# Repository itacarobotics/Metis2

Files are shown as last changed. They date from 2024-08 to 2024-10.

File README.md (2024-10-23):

# Metis2
Metis2 is the latest enhanced version of Metis. This project is currently under development, however below is an overview of the changes.

## Mechanics
The new delta robot provides a modular design, with less components and assembly time. An extra degree of freedom has been added to the end effector to rotate around the z-axis. Furthermore, the size of the new robot is significantly smaller than the previous one, therefore it can better fits in smaller environments, such as a small production line.

## Electronics
The control unit of the robot is the BIGTREETECH-SKR-mini-E3 board, which is a main board for 3D printers. Beyond that, a custom PCB has been designed as a shield for the main board, in order to better manage GPIOs and power supply for encoders and motors using terminal blocks.

## Firmware
The control software of the robot is subdivided in two parts based on abstraction levels. The low-level firmware runs on an STM32-G01B1RCT6 micro-controller integrated onto the motherboard. The firmware runs different state machines, each responisble for the comunication, processing data for the trajectory generation and inverse geometry and controlling the closed loop stepper motors. The higher level software controls the position of the robot using the GCODE format.

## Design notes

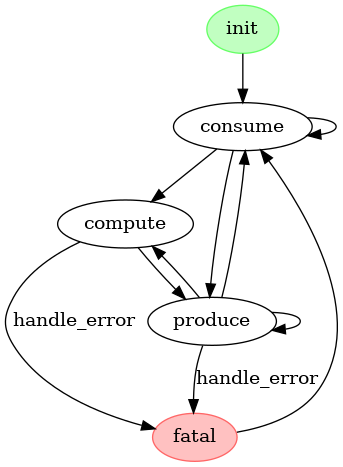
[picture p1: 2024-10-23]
firmware/assets/gv_fsm/_fsm_middleware.dot.png

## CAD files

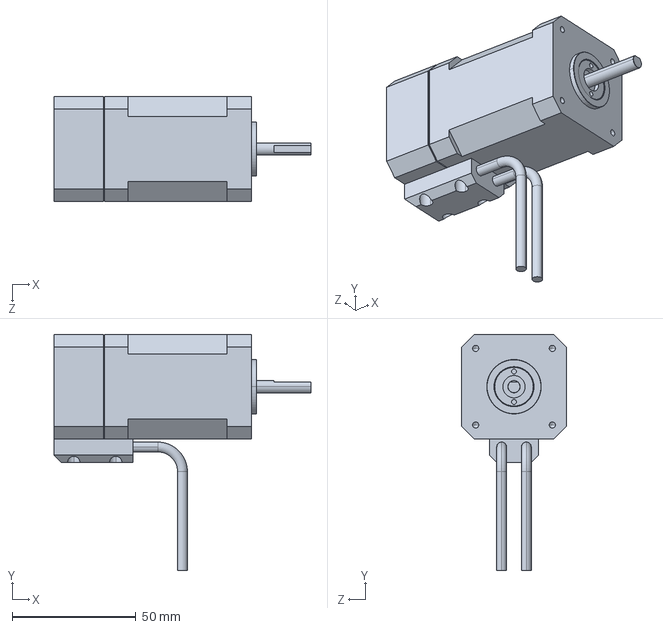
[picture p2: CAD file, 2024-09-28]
doc/motors/17HS24-2004D-E1K/17HS24-2004D-E1K.STEP
104.0 x 95.5 x 42.3 mm

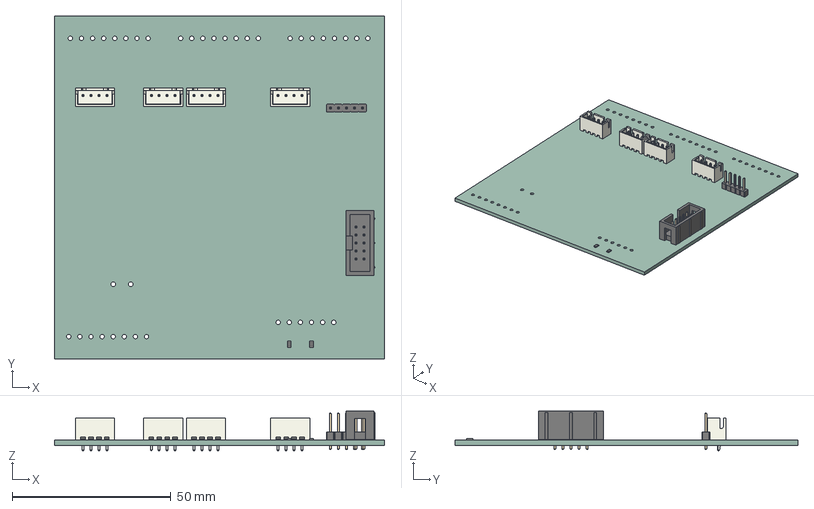
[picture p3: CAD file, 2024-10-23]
hardware/BTT-SKR-MINI-E3_shield/BTT-SKR-MINI-E3_shield.step
104.0 x 108.0 x 12.5 mm
JST_B4B_XH_A x 4
R_0805_2012Metric x 2
PinHeader_1x05_P254mm_Vertical
IDC_Header_2x05_P254mm_Vertical
BTT-SKR-MINI-E3_shield_PCB

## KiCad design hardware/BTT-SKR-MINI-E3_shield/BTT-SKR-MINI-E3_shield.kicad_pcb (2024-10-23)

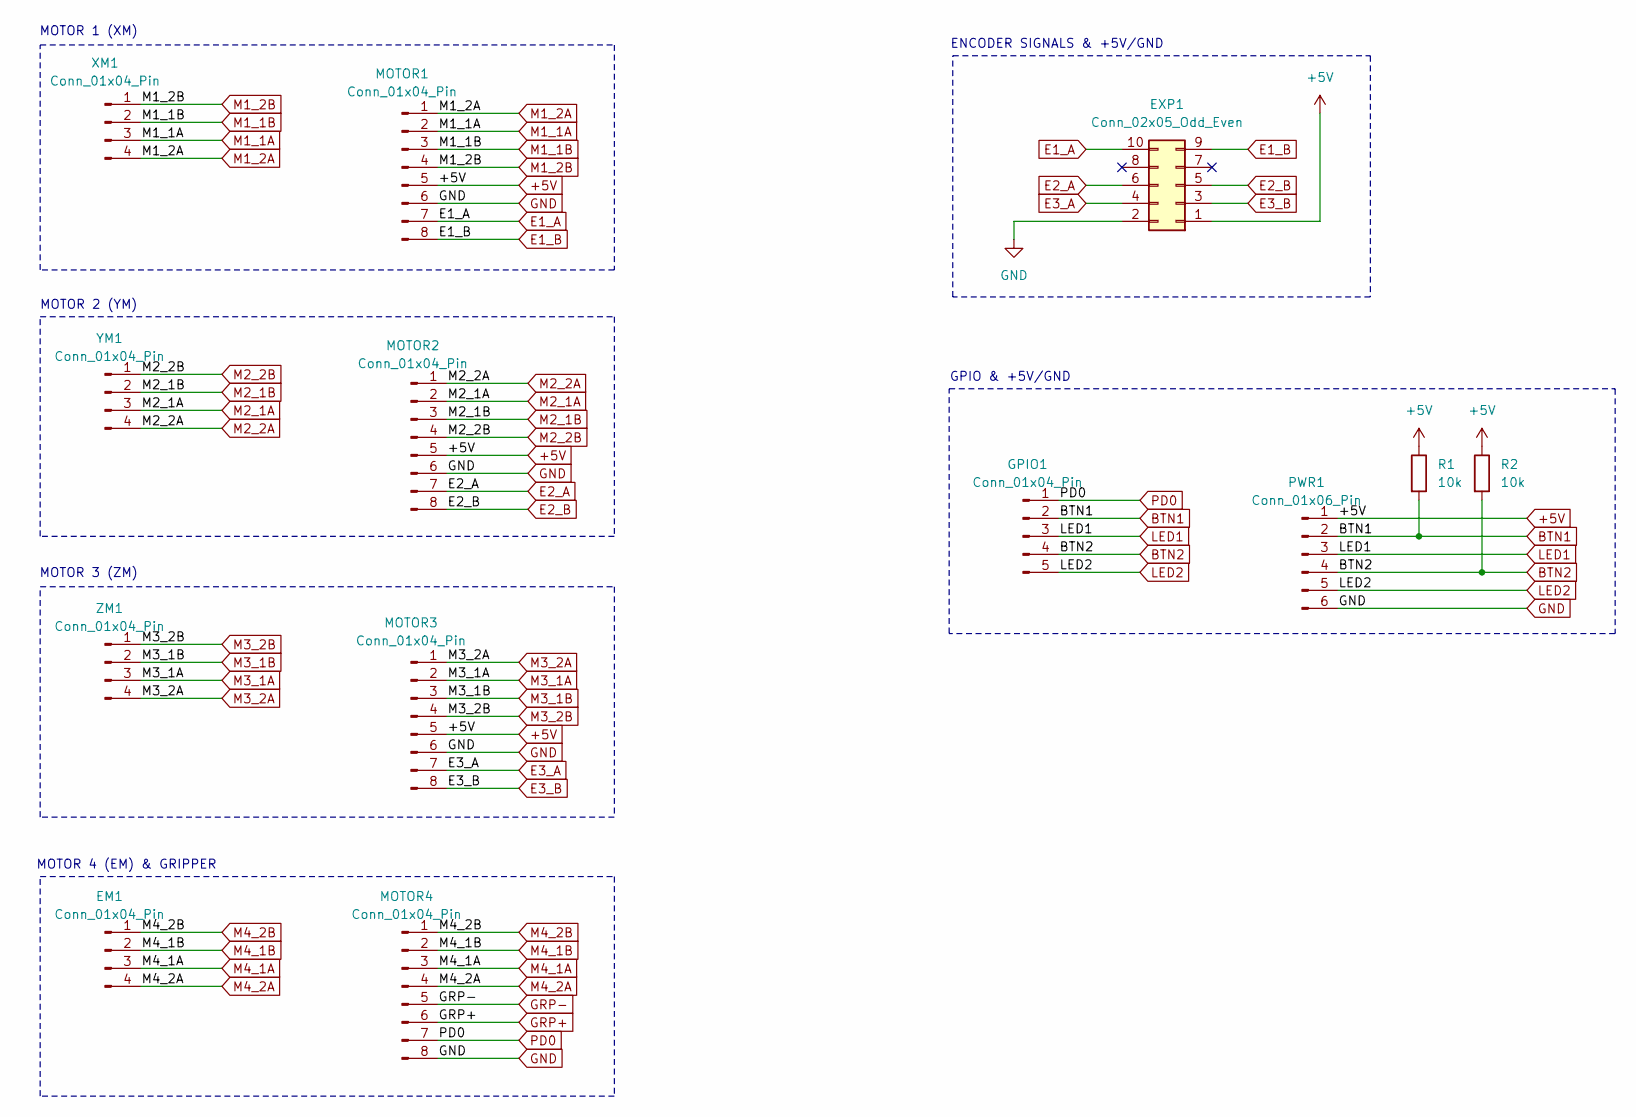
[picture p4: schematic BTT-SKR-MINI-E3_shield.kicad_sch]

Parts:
EM1: Conn_01x04_Pin; JST_XH_B4B-XH-A_1x04_P2.50mm_Vertical
EXP1: Conn_02x05_Odd_Even; IDC-Header_2x05_P2.54mm_Vertical
GPIO1: Conn_01x04_Pin; PinHeader_1x05_P2.54mm_Vertical
MOTOR1, MOTOR2, MOTOR3, MOTOR4: Conn_01x04_Pin; MC1.5_8-G-3.5
PWR1: Conn_01x06_Pin; MV1.5_6-G-3.5
R1, R2: 10k; R_0805_2012Metric
XM1: Conn_01x04_Pin; JST_XH_B4B-XH-A_1x04_P2.50mm_Vertical
YM1: Conn_01x04_Pin; JST_XH_B4B-XH-A_1x04_P2.50mm_Vertical
ZM1: Conn_01x04_Pin; JST_XH_B4B-XH-A_1x04_P2.50mm_Vertical

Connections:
+5V: EXP1.1, MOTOR1.5, MOTOR2.5, MOTOR3.5, PWR1.1, R1.1, R2.1
BTN1: GPIO1.2, PWR1.2, R1.2
BTN2: GPIO1.4, PWR1.4, R2.2
E1_A: EXP1.10, MOTOR1.7
E1_B: EXP1.9, MOTOR1.8
E2_A: EXP1.6, MOTOR2.7
E2_B: EXP1.5, MOTOR2.8
E3_A: EXP1.4, MOTOR3.7
E3_B: EXP1.3, MOTOR3.8
GND: EXP1.2, MOTOR1.6, MOTOR2.6, MOTOR3.6, MOTOR4.8, PWR1.6
GRP+: MOTOR4.6; also elsewhere on the board
GRP-: MOTOR4.5; also elsewhere on the board
LED1: GPIO1.3, PWR1.3
LED2: GPIO1.5, PWR1.5
M1_1A: MOTOR1.2, XM1.3
M1_1B: MOTOR1.3, XM1.2
M1_2A: MOTOR1.1, XM1.4
M1_2B: MOTOR1.4, XM1.1
M2_1A: MOTOR2.2, YM1.3
M2_1B: MOTOR2.3, YM1.2
M2_2A: MOTOR2.1, YM1.4
M2_2B: MOTOR2.4, YM1.1
M3_1A: MOTOR3.2, ZM1.3
M3_1B: MOTOR3.3, ZM1.2
M3_2A: MOTOR3.1, ZM1.4
M3_2B: MOTOR3.4, ZM1.1
M4_1A: EM1.3, MOTOR4.3
M4_1B: EM1.2, MOTOR4.2
M4_2A: EM1.4, MOTOR4.4
M4_2B: EM1.1, MOTOR4.1
PD0: GPIO1.1, MOTOR4.7

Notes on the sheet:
ENCODER SIGNALS & +5V/GND
MOTOR 3 (ZM)
MOTOR 4 (EM) & GRIPPER
MOTOR 1 (XM)
GPIO & +5V/GND
MOTOR 2 (YM)

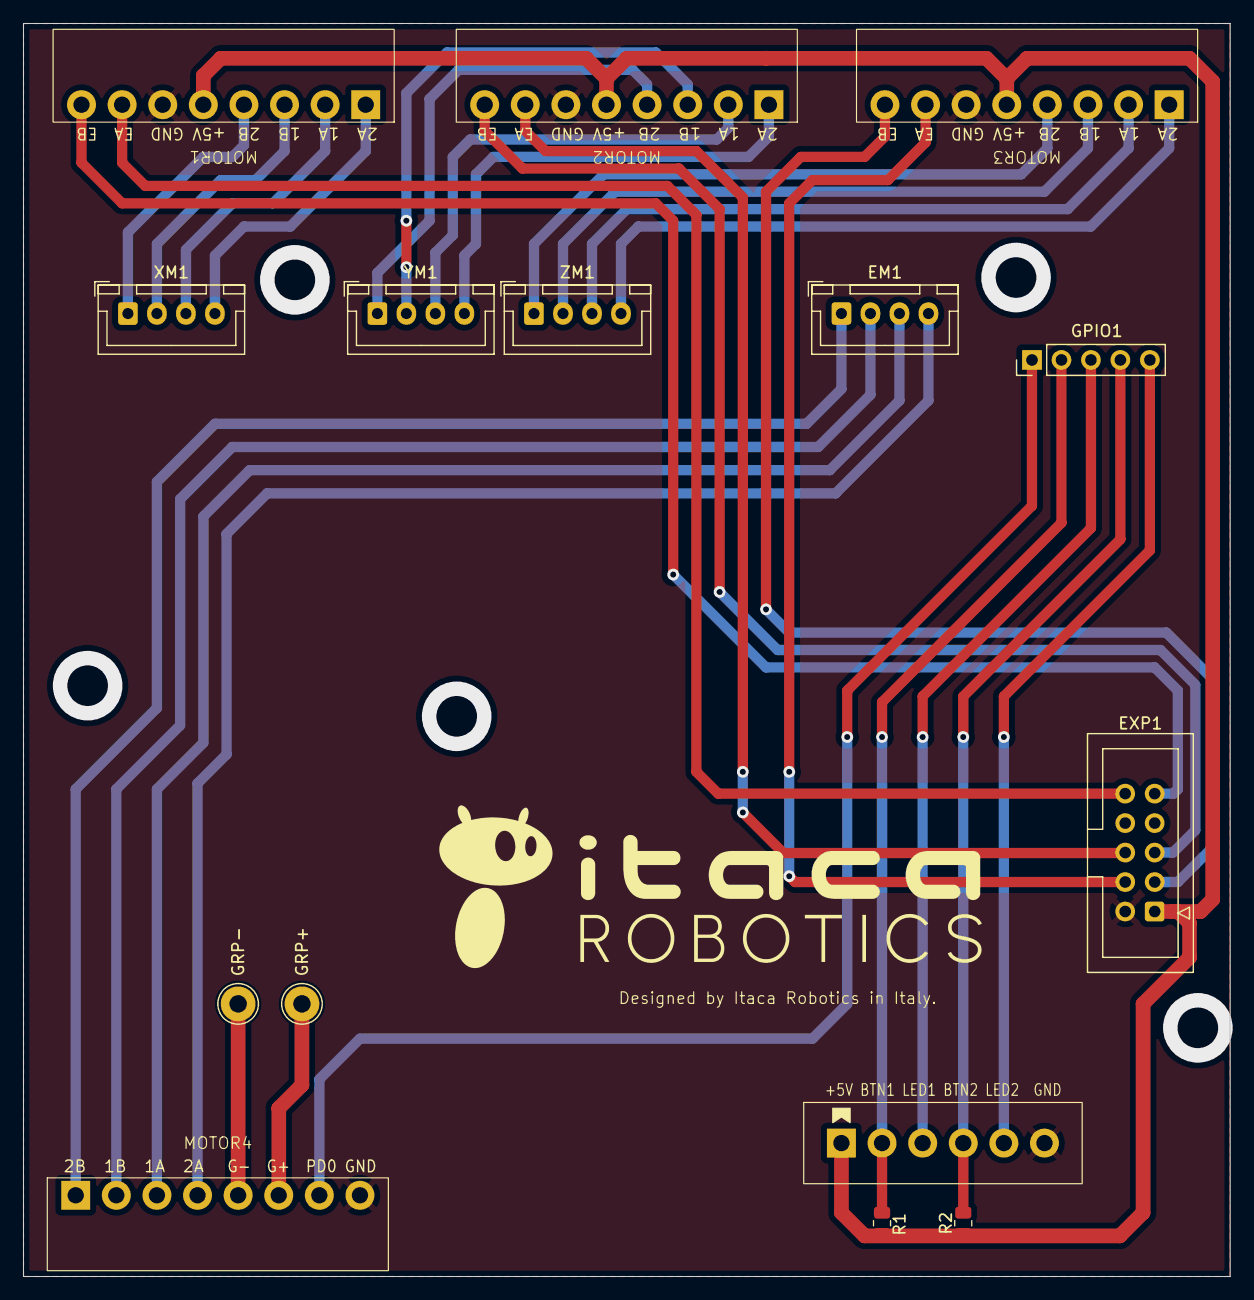
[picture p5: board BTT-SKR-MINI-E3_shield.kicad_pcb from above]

Board: 2 copper layers, 104.0 x 108.0 mm, 15 parts (0 on the bottom side), 31 nets.

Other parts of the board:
GRP+: TestPoint_THTPad_D3.0mm_Drill1.5mm
GRP-: TestPoint_THTPad_D3.0mm_Drill1.5mm

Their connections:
GRP+: GRP+.1; also elsewhere on the board
GRP-: GRP-.1; also elsewhere on the board

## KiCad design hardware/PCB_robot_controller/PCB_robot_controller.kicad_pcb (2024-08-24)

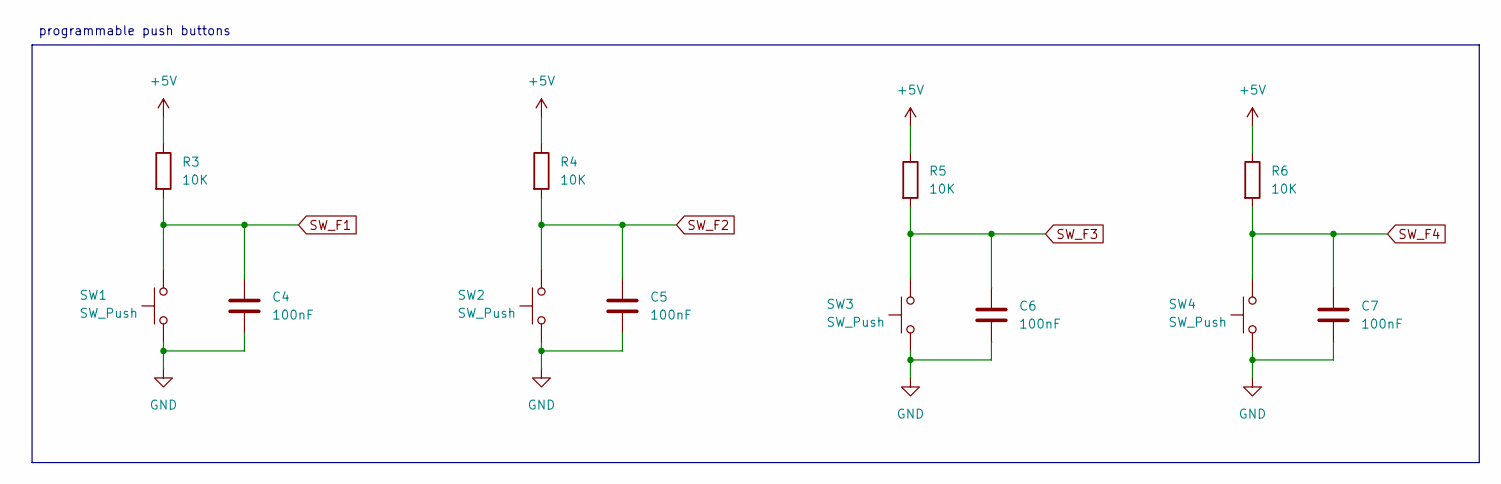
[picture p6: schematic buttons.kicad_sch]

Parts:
C4, C5, C6, C7: 100nF; C_0805_2012Metric
R3, R4, R5, R6: 10K; R_0805_2012Metric
SW1, SW2, SW3, SW4: SW_Push; SW_PUSH_6mm_H5mm

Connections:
+5V: R3.1, R4.1, R5.1, R6.1; also elsewhere on the board
GND: C4.2, C5.2, C6.2, C7.2, SW1.1, SW2.1, SW3.1, SW4.1; also elsewhere on the board
SW_F1: C4.1, R3.2, SW1.2; also elsewhere on the board
SW_F2: C5.1, R4.2, SW2.2; also elsewhere on the board
SW_F3: C6.1, R5.2, SW3.2; also elsewhere on the board
SW_F4: C7.1, R6.2, SW4.2; also elsewhere on the board

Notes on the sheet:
programmable push buttons

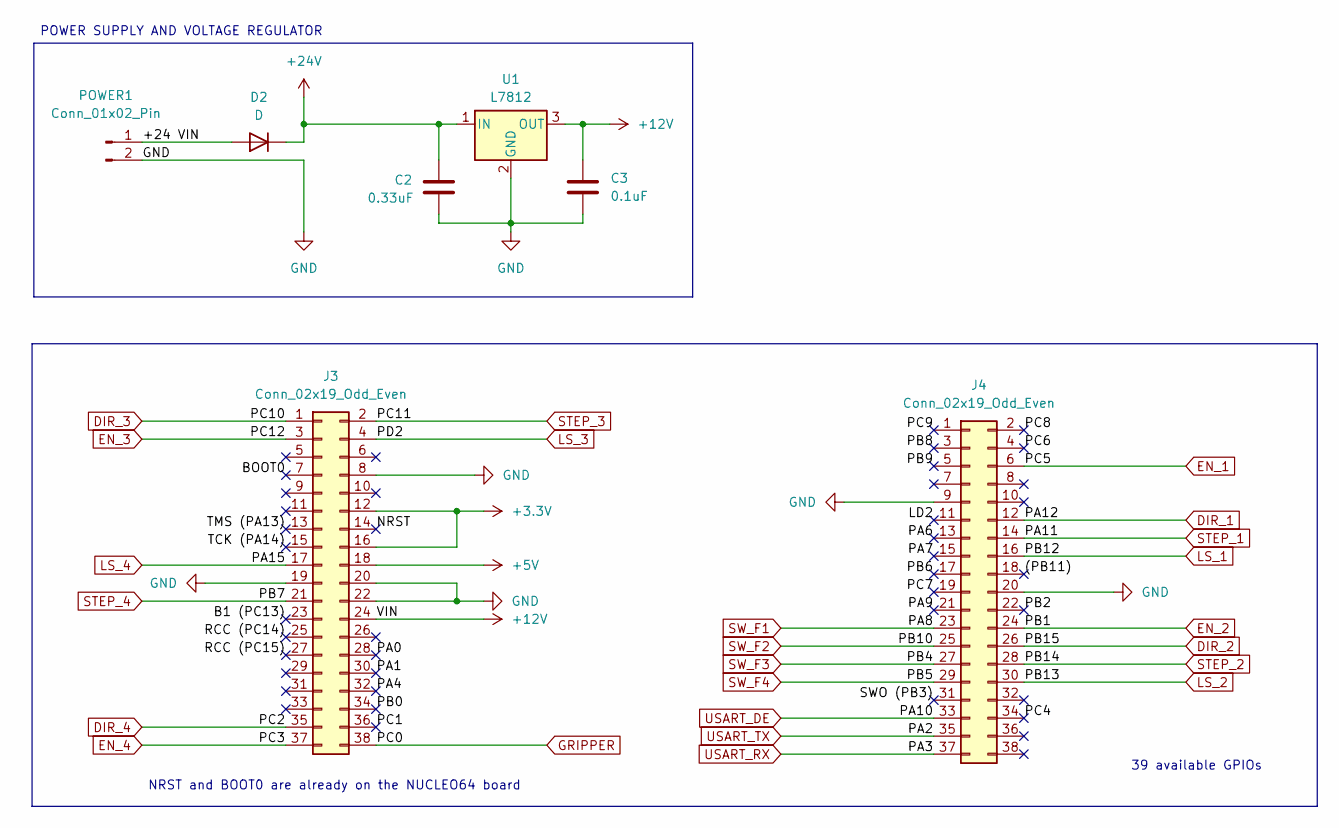
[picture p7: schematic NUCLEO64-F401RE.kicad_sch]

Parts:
C2: 0.33uF; C_0805_2012Metric
C3: 0.1uF; C_0805_2012Metric
D2: D; D_0805_2012Metric
J3, J4: Conn_02x19_Odd_Even; PinSocket_2x19_P2.54mm_Vertical
POWER1: Conn_01x02_Pin; TerminalBlock 45 degrees, pitch 3.5mm, 2 pins, WAGO 250-102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
U1: L7812; TO-220-3_Horizontal_TabDown

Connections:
+3.3V: J3.12, J3.16
+5V: J3.18; also elsewhere on the board
+12V: C3.1, J3.24, U1.3 (OUT)
+24V: C2.1, D2.1 (K), U1.1 (IN); also elsewhere on the board
/NUCLEO64-F401RE/(PB11): J4.18
/NUCLEO64-F401RE/+24 VIN: D2.2 (A), POWER1.1; also elsewhere on the board
/NUCLEO64-F401RE/B1 (PC13): J3.23
/NUCLEO64-F401RE/BOOT0: J3.7
/NUCLEO64-F401RE/LD2: J4.11
/NUCLEO64-F401RE/NRST: J3.14
/NUCLEO64-F401RE/PA0: J3.28
/NUCLEO64-F401RE/PA1: J3.30
/NUCLEO64-F401RE/PA4: J3.32
/NUCLEO64-F401RE/PA6: J4.13
/NUCLEO64-F401RE/PA7: J4.15
/NUCLEO64-F401RE/PA9: J4.21
/NUCLEO64-F401RE/PB0: J3.34
/NUCLEO64-F401RE/PB2: J4.22
/NUCLEO64-F401RE/PB6: J4.17
/NUCLEO64-F401RE/PB8: J4.3
/NUCLEO64-F401RE/PB9: J4.5
/NUCLEO64-F401RE/PC1: J3.36
/NUCLEO64-F401RE/PC4: J4.34
/NUCLEO64-F401RE/PC6: J4.4
/NUCLEO64-F401RE/PC7: J4.19
/NUCLEO64-F401RE/PC8: J4.2
/NUCLEO64-F401RE/PC9: J4.1
/NUCLEO64-F401RE/RCC (PC14): J3.25
/NUCLEO64-F401RE/RCC (PC15): J3.27
/NUCLEO64-F401RE/SWO (PB3): J4.31
/NUCLEO64-F401RE/TCK (PA14): J3.15
/NUCLEO64-F401RE/TMS (PA13): J3.13
DIR_1: J4.12; also elsewhere on the board
DIR_2: J4.26; also elsewhere on the board
DIR_3: J3.1; also elsewhere on the board
DIR_4: J3.35; also elsewhere on the board
EN_1: J4.6; also elsewhere on the board
EN_2: J4.24; also elsewhere on the board
EN_3: J3.3; also elsewhere on the board
EN_4: J3.37; also elsewhere on the board
GND: C2.2, C3.2, J3.8, J3.19, J3.20, J3.22, J4.9, J4.20, POWER1.2, U1.2 (GND); also elsewhere on the board
GRIPPER: J3.38; also elsewhere on the board
LS_1: J4.16; also elsewhere on the board
LS_2: J4.30; also elsewhere on the board
LS_3: J3.4; also elsewhere on the board
LS_4: J3.17; also elsewhere on the board
STEP_1: J4.14; also elsewhere on the board
STEP_2: J4.28; also elsewhere on the board
STEP_3: J3.2; also elsewhere on the board
STEP_4: J3.21; also elsewhere on the board
SW_F1: J4.23; also elsewhere on the board
SW_F2: J4.25; also elsewhere on the board
SW_F3: J4.27; also elsewhere on the board
SW_F4: J4.29; also elsewhere on the board
USART_DE: J4.33; also elsewhere on the board
USART_RX: J4.37; also elsewhere on the board
USART_TX: J4.35; also elsewhere on the board

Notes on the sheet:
39 available GPIOs
POWER SUPPLY AND VOLTAGE REGULATOR
NRST and BOOT0 are already on the NUCLEO64 board

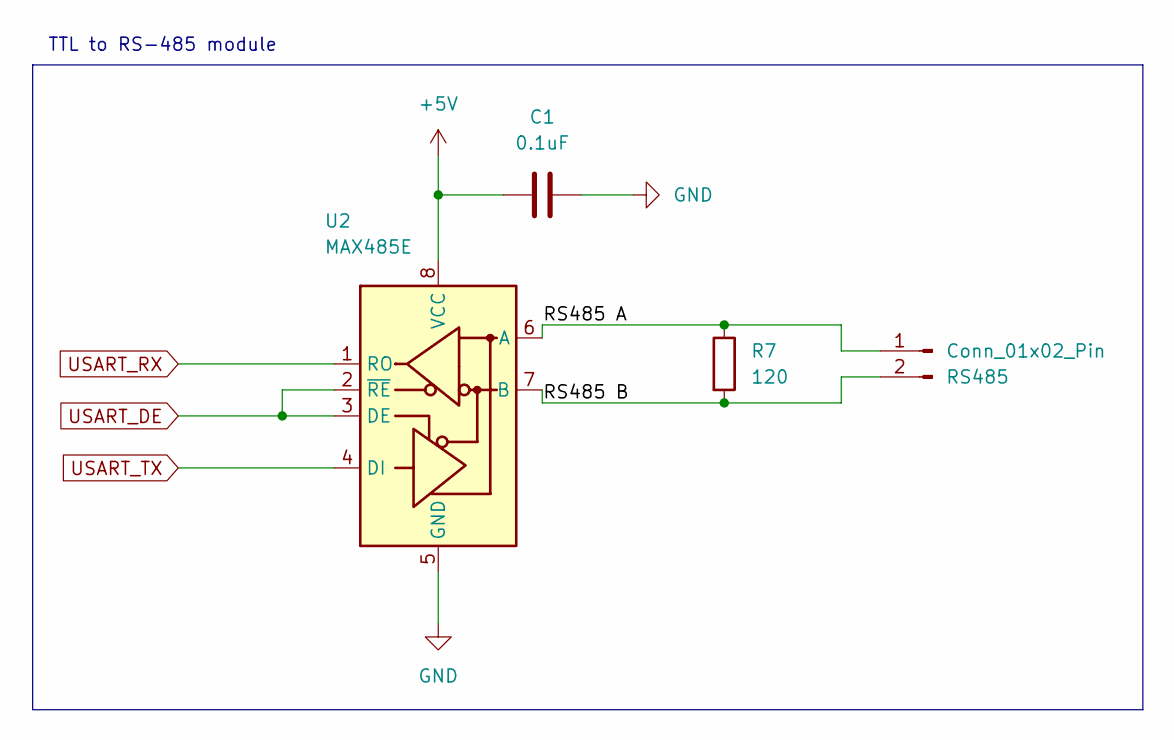
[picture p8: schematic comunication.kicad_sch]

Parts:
C1: 0.1uF; C_0805_2012Metric
R7: 120; R_0805_2012Metric
RS485: Conn_01x02_Pin; TerminalBlock 45 degrees, pitch 3.5mm, 2 pins, WAGO 250-102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
U2: MAX485E; SO-8_3.9x4.9mm_P1.27mm

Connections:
+5V: C1.1, U2.8 (VCC); also elsewhere on the board
/comunication/RS485 A: R7.1, RS485.1, U2.6 (A); also elsewhere on the board
/comunication/RS485 B: R7.2, RS485.2, U2.7 (B); also elsewhere on the board
GND: C1.2, U2.5 (GND); also elsewhere on the board
USART_DE: U2.2 (~RE), U2.3 (DE); also elsewhere on the board
USART_RX: U2.1 (RO); also elsewhere on the board
USART_TX: U2.4 (DI); also elsewhere on the board

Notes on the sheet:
TTL to RS-485 module

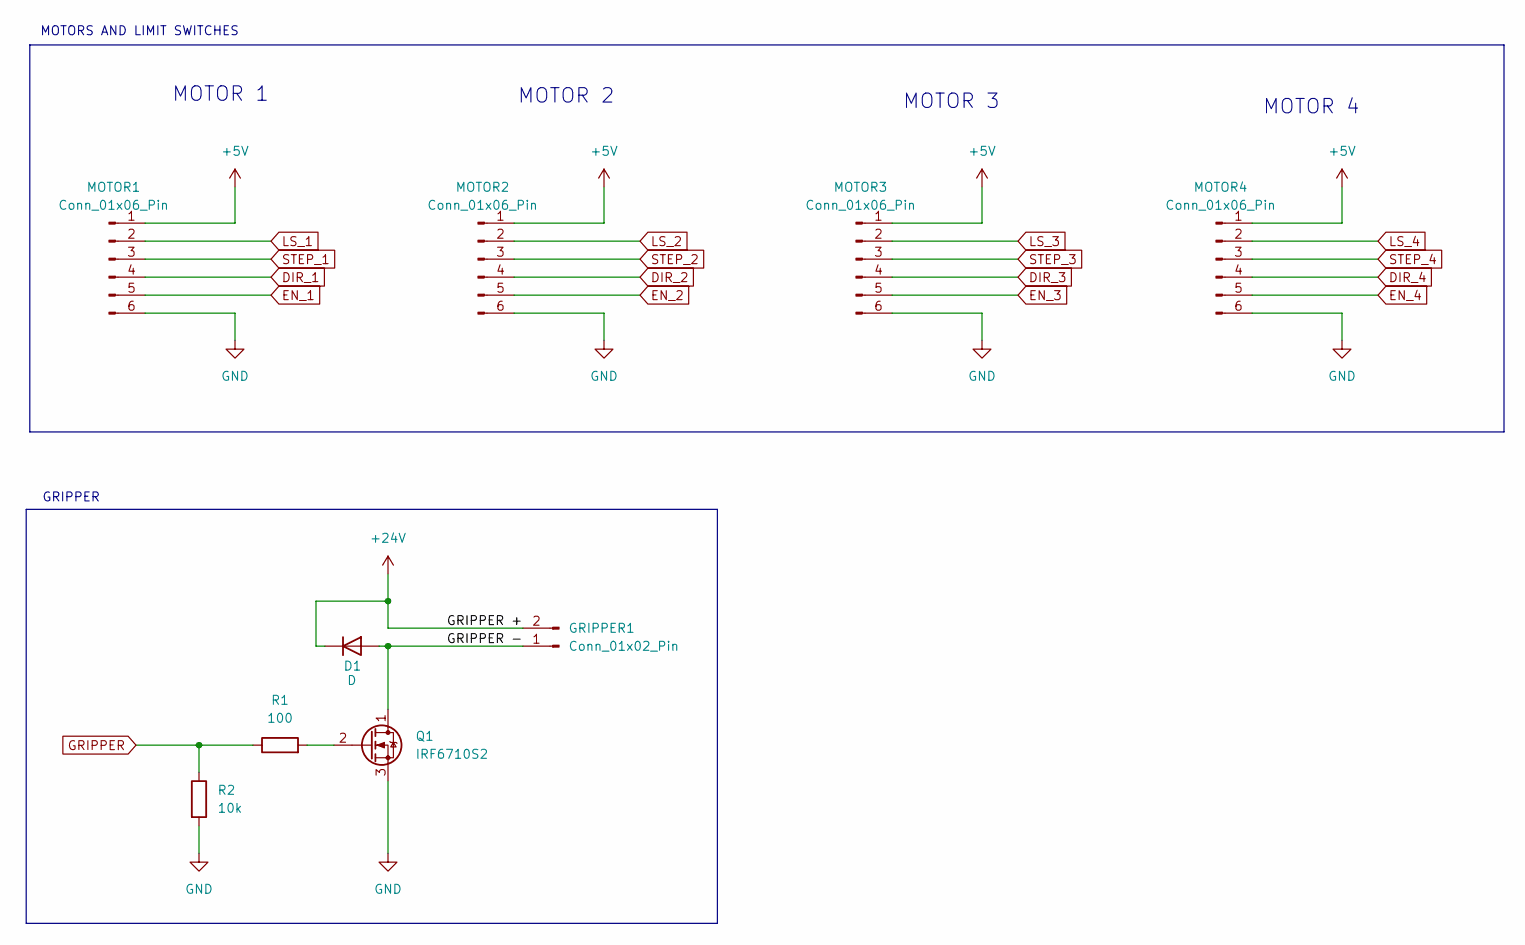
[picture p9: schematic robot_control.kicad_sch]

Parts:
D1: D; D_0805_2012Metric
GRIPPER1: Conn_01x02_Pin; TerminalBlock 45 degrees, pitch 3.5mm, 2 pins, WAGO 250-102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
MOTOR1, MOTOR2, MOTOR3, MOTOR4: Conn_01x06_Pin; TerminalBlock 45 degrees, pitch 3.5mm, 6 pins, WAGO 250-102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
Q1: IRF6710S2; TO-220-3_Horizontal_TabDown
R1: 100; R_0805_2012Metric
R2: 10k; R_0805_2012Metric

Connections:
+5V: MOTOR1.1, MOTOR2.1, MOTOR3.1, MOTOR4.1; also elsewhere on the board
+24V: D1.1 (K), GRIPPER1.2; also elsewhere on the board
/robot_control/GRIPPER -: D1.2 (A), GRIPPER1.1, Q1.1 (D); also elsewhere on the board
DIR_1: MOTOR1.4; also elsewhere on the board
DIR_2: MOTOR2.4; also elsewhere on the board
DIR_3: MOTOR3.4; also elsewhere on the board
DIR_4: MOTOR4.4; also elsewhere on the board
EN_1: MOTOR1.5; also elsewhere on the board
EN_2: MOTOR2.5; also elsewhere on the board
EN_3: MOTOR3.5; also elsewhere on the board
EN_4: MOTOR4.5; also elsewhere on the board
GND: MOTOR1.6, MOTOR2.6, MOTOR3.6, MOTOR4.6, Q1.3 (S), R2.2; also elsewhere on the board
GRIPPER: R1.1, R2.1; also elsewhere on the board
LS_1: MOTOR1.2; also elsewhere on the board
LS_2: MOTOR2.2; also elsewhere on the board
LS_3: MOTOR3.2; also elsewhere on the board
LS_4: MOTOR4.2; also elsewhere on the board
unnamed: Q1.2 (G), R1.2
STEP_1: MOTOR1.3; also elsewhere on the board
STEP_2: MOTOR2.3; also elsewhere on the board
STEP_3: MOTOR3.3; also elsewhere on the board
STEP_4: MOTOR4.3; also elsewhere on the board

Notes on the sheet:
MOTOR 2
MOTOR 4
MOTORS AND LIMIT SWITCHES
MOTOR 3
GRIPPER
MOTOR 1

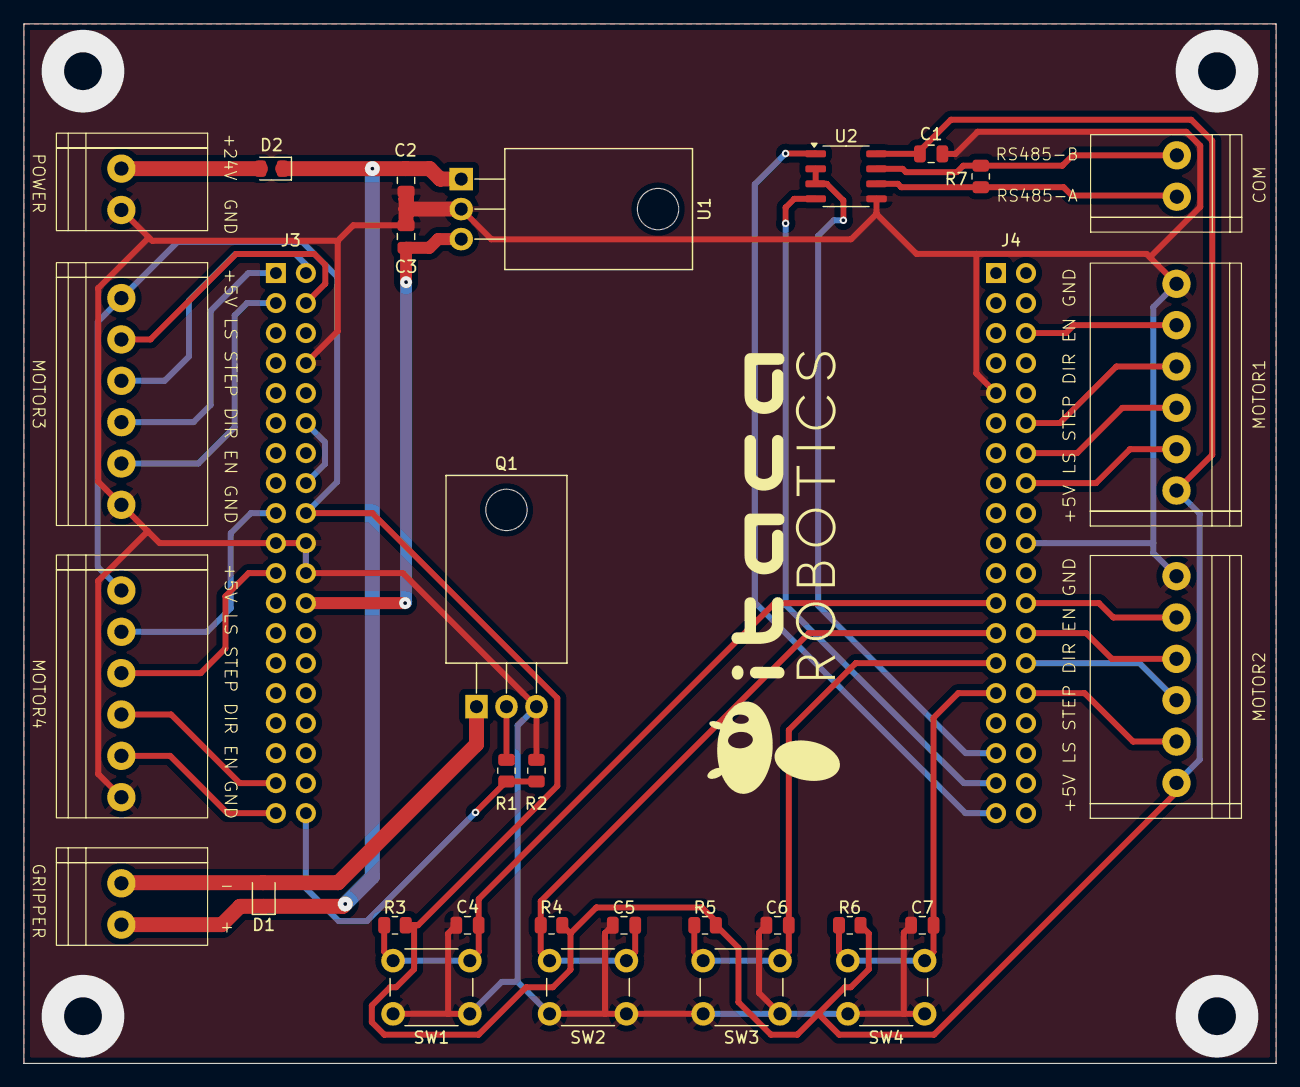
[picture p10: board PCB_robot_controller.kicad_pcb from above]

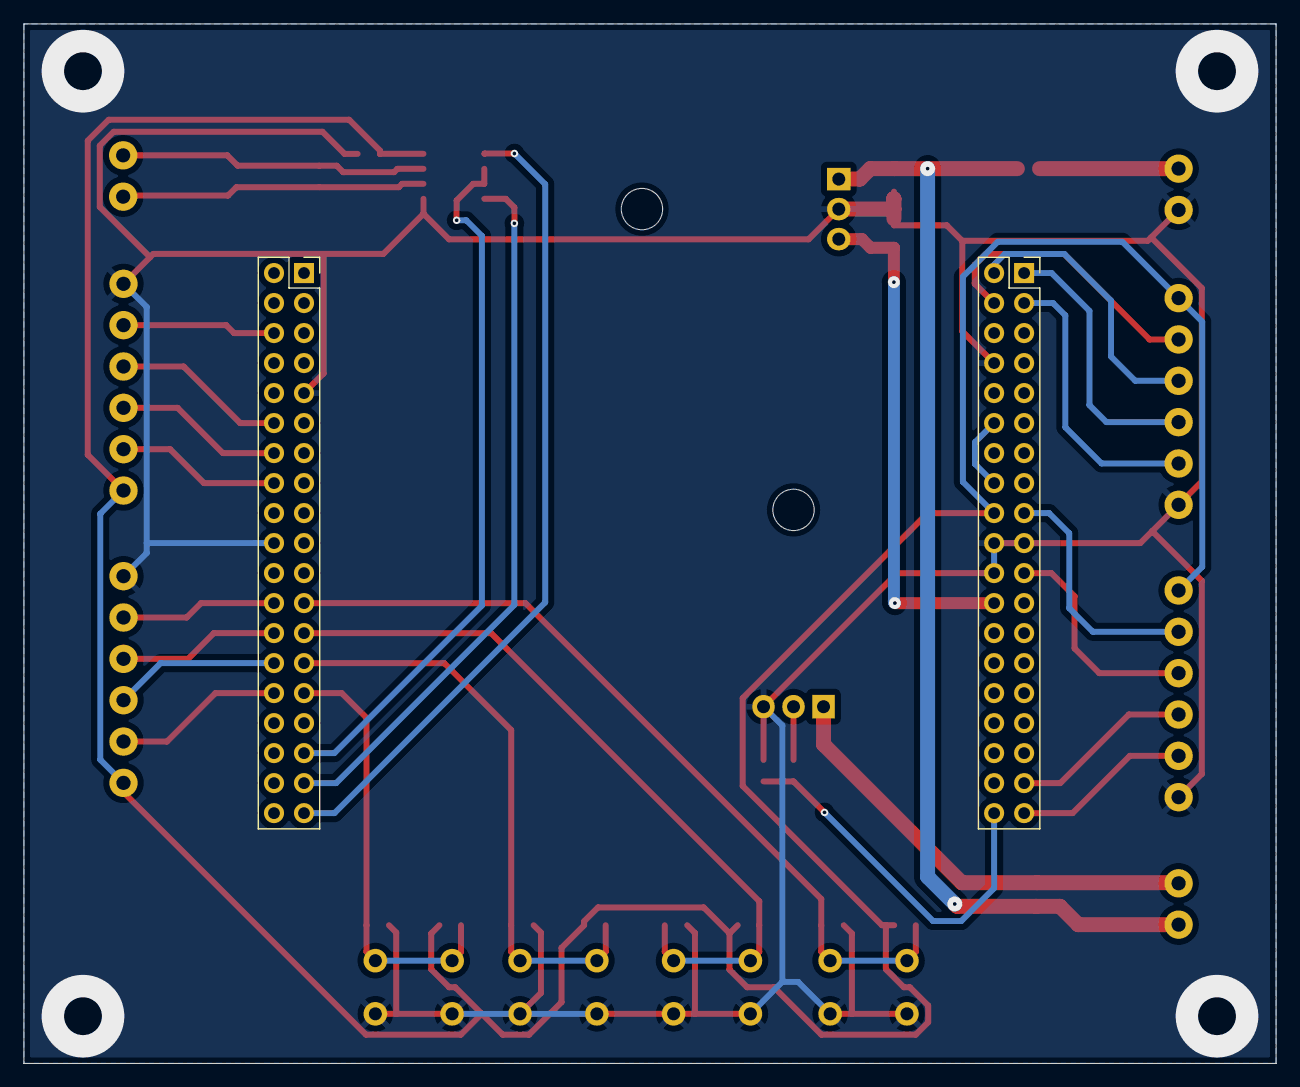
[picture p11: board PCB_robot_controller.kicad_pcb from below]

Board: 2 copper layers, 106.0 x 88.0 mm, 32 parts (2 on the bottom side), 34 nets.

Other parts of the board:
COM: Conn_01x02_Pin; TerminalBlock 45 degrees, pitch 3.5mm, 2 pins, WAGO 250-102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
GRIPPER: Conn_01x02_Pin; TerminalBlock 45 degrees, pitch 3.5mm, 2 pins, WAGO 250-102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
POWER: Conn_01x02_Pin; TerminalBlock 45 degrees, pitch 3.5mm, 2 pins, WAGO 250-102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

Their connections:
+24V: GRIPPER.2; also elsewhere on the board
/NUCLEO64-F401RE/+24 VIN: POWER.1; also elsewhere on the board
/comunication/RS485 A: COM.1; also elsewhere on the board
/comunication/RS485 B: COM.2; also elsewhere on the board
/robot_control/GRIPPER -: GRIPPER.1; also elsewhere on the board
GND: POWER.2; also elsewhere on the board

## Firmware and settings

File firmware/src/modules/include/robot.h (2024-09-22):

#ifndef ROBOT_H
#define ROBOT_H


/*
 * @brief Robot's important parameters.
 *
 * See implementation file for information about this module.
 *
 * MIT License
 * 
 * Copyright (c) 2024 Federico Osti
 * 
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
 * THE SOFTWARE IS PROVIDED "AS IS", WITHOUT WARRANTY OF ANY KIND, EXPRESS OR
 * IMPLIED, INCLUDING BUT NOT LIMITED TO THE WARRANTIES OF MERCHANTABILITY,
 * FITNESS FOR A PARTICULAR PURPOSE AND NONINFRINGEMENT. IN NO EVENT SHALL THE
 * AUTHORS OR COPYRIGHT HOLDERS BE LIABLE FOR ANY CLAIM, DAMAGES OR OTHER
 * LIABILITY, WHETHER IN AN ACTION OF CONTRACT, TORT OR OTHERWISE, ARISING FROM,
 * OUT OF OR IN CONNECTION WITH THE SOFTWARE OR THE USE OR OTHER DEALINGS IN THE
 * SOFTWARE.
 */


#include "gcode.h"

////////////////////////////////////////////////////////////////////////////////
// Common macros
////////////////////////////////////////////////////////////////////////////////

// robot's kinematics properties
#define BASE_RADIUS                     60      // [ mm ]
#define BICEPS_LENGTH                   80      // [ mm ]
#define FOREARM_LENGTH                  120     // [ mm ]
#define EE_RADIUS                       20      // [ mm ]

#define JOINT_LIMIT_MIN                -999
#define JOINT_LIMIT_MAX                 999

#define POSITION_HOME_OFFSET_Z         -80

#define VIA_POINTS_TIME_STEP            0.01

// robot's dynamics properties
#define MAX_LINEAR_VEL                  800     // [ mm/s ]
#define MAX_LINEAR_ACC                  20000    // [ mm/s2 ]
#define MAX_ROTATION_VEL                20      // [ rad/s ]
#define MAX_ROTATION_ACC                50      // [ rad/s2 ]


////////////////////////////////////////////////////////////////////////////////
// Type definitions
////////////////////////////////////////////////////////////////////////////////

typedef enum
{
    ROBOT_RUN,
    ROBOT_IDLE,
    ROBOT_DWELL,
    ROBOT_ERROR,
    ROBOT_NOT_CALIBRATED,

    ROBOT_SOFT_BREAK,         // the goal position is reached and then break
    ROBOT_HARD_BREAK,         // it stops with motors enabled
    ROBOT_EMERGENCY_STOP      // it stops with motors disabled
} robot_status_t;

typedef struct
{
    robot_status_t  status;
    gcode_data_t    pos;
} robot_info_t;


////////////////////////////////////////////////////////////////////////////////
// Public (global) externs
////////////////////////////////////////////////////////////////////////////////

extern robot_info_t  robot_info;

////////////////////////////////////////////////////////////////////////////////
// Public (global) function declarations
////////////////////////////////////////////////////////////////////////////////



#endif // ROBOT_H

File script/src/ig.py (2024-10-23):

import numpy as np
import matplotlib.pyplot as plt
from mpl_toolkits.mplot3d import Axes3D

import robot

# Delta Robot Parameters
R1 = robot.BASE_RADIUS
L1 = robot.BICEPS_LEN
L2 = robot.FOREARM_LEN
R2 = robot.EE_RADIUS


def compute_angle_YZ(x, y, z):

    d = R1 - y - R2
    theta = abs(np.atan2(z, d))

    a = np.sqrt(L2*L2 - x*x)
    c = np.sqrt(d*d + z*z)

    k = (L1*L1 + c*c - a*a) / (2 * L1 * c)
    if k > 1:
        print(f"k: {k}")
        return None
    
    alpha = abs(np.acos(k))

    q_i = (theta + alpha) - np.pi

    return q_i



def inverse_geometry(x, y, z):
    
    x1 = x
    y1 = y
    z1 = z
    q1 = compute_angle_YZ(x1, y1, z1)
    if q1 is None:
        return None
    
    x2 = x*np.cos(2*np.pi/3) - y*np.sin(2*np.pi/3)
    y2 = x*np.sin(2*np.pi/3) + y*np.cos(2*np.pi/3)
    z2 = z
    q2 = compute_angle_YZ(x2, y2, z2)
    if q2 is None:
        return None
    
    x3 = x*np.cos(-2*np.pi/3) - y*np.sin(-2*np.pi/3)
    y3 = x*np.sin(-2*np.pi/3) + y*np.cos(-2*np.pi/3)
    z3 = z
    q3 = compute_angle_YZ(x3, y3, z3)
    if q3 is None:
        return None

    return np.array([q1, q2, q3])




# Function to calculate the position of the end effector from given angles
def forward_geometry(q, x):
    # Coordinates of the base joints
    bs_joints = [
        [R1 * np.sin(np.deg2rad(0)),    R1 * np.cos(np.deg2rad(0)),     0],
        [R1 * np.sin(np.deg2rad(120)),  R1 * np.cos(np.deg2rad(120)),   0],
        [R1 * np.sin(np.deg2rad(240)),  R1 * np.cos(np.deg2rad(240)),   0]
    ]

    el_joint1 = bs_joints[0] + np.array([0 , L1 * np.cos(q[0]), L1 * np.sin(q[0])])
    el_joint2 = bs_joints[1] + np.array([L1 * np.cos(q[1]) * np.sin(np.deg2rad(120)), L1 * np.cos(q[1]) * np.cos(np.deg2rad(120)), L1 * np.sin(q[1])])
    el_joint3 = bs_joints[2] + np.array([L1 * np.cos(q[2]) * np.sin(np.deg2rad(240)), L1 * np.cos(q[2]) * np.cos(np.deg2rad(240)), L1 * np.sin(q[2])])
    el_joints = np.array([el_joint1, el_joint2, el_joint3])

    ee_joint1 = [x[0] + R2 * np.sin(np.deg2rad(0)),    x[1] + R2 * np.cos(np.deg2rad(0)),   x[2]]
    ee_joint2 = [x[0] + R2 * np.sin(np.deg2rad(120)),  x[1] + R2 * np.cos(np.deg2rad(120)), x[2]]
    ee_joint3 = [x[0] + R2 * np.sin(np.deg2rad(240)),  x[1] + R2 * np.cos(np.deg2rad(240)), x[2]]
    ee_joints = np.array([ee_joint1, ee_joint2, ee_joint3])
    
    return np.array(bs_joints), el_joints, ee_joints




# Function to plot the delta robot in 3D
def plot_delta_robot_3d(x_ee, y_ee, z_ee):
    fig = plt.figure()
    ax = fig.add_subplot(111, projection='3d')
    

    # Calculate inverse kinematics for the given end effector position
    q = inverse_geometry(x_ee, y_ee, z_ee)
    if q is None:
        print("[ERROR!] Solution not found.")
        return None
    
    print(q)
    
    # Calculate the positions of the elbow joints
    base_joints, elbow_joints ,end_effector_joints = forward_geometry(q, np.array([x_ee, y_ee, z_ee]))
    
    # Plot the base joints
    ax.scatter(base_joints[:, 0], base_joints[:, 1], base_joints[:, 2], c='b', label='Base Joints')
    


    # Plot the elbow joints
    ax.scatter(elbow_joints[:, 0], elbow_joints[:, 1], elbow_joints[:, 2], c='g', label='Ebow Joints')

    # Plot the end effector joints
    ax.scatter(end_effector_joints[:, 0], end_effector_joints[:, 1], end_effector_joints[:, 2], c='r', label='End Effector')


    # Plot the arms (upper arms)
    for i in range(3):
        # Plot upper arm
        ax.plot([base_joints[i][0], elbow_joints[i][0]], 
                [base_joints[i][1], elbow_joints[i][1]], 
                [base_joints[i][2], elbow_joints[i][2]], 'g-', label='Upper Arm' if i == 0 else "")
        
        # Plot lower arm
        ax.plot([elbow_joints[i][0], end_effector_joints[i][0]], 
                [elbow_joints[i][1], end_effector_joints[i][1]], 
                [elbow_joints[i][2], end_effector_joints[i][2]], 'g-', label='Upper Arm' if i == 0 else "")
        

    print(np.linalg.norm(base_joints[0] - elbow_joints[0]))
    print(np.linalg.norm(base_joints[1] - elbow_joints[1]))
    print(np.linalg.norm(base_joints[2] - elbow_joints[2]))

    print(np.linalg.norm(-end_effector_joints[0] + elbow_joints[0]))
    print(np.linalg.norm(-end_effector_joints[1] + elbow_joints[1]))
    print(np.linalg.norm(-end_effector_joints[2] + elbow_joints[2]))

    print(elbow_joints)
    print(end_effector_joints)

    # Set plot limits and labels
    ax.set_xlim([-100, 100])
    ax.set_ylim([-100, 100])
    ax.set_zlim([-200, 15])
    ax.set_xlabel('X')
    ax.set_ylabel('Y')
    ax.set_zlabel('Z')
    ax.set_title('Delta Robot 3D Visualization')
    ax.legend()
    plt.show()









def main():
    
    # Test with specific end-effector positions
    x_ee, y_ee, z_ee = 50, 0, -139  # Desired end-effector position (x, y, z)
    plot_delta_robot_3d(x_ee, y_ee, z_ee)

    return


if __name__ == "__main__":
    main()

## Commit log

2024-08-24 pcb to production
    [NUCLEO64-F401RE.kicad_sch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]
2024-09-04 added modules
    [PCB_robot_controller.kicad_sch]
2024-09-09 trajectory planning works
    [configuration.h, trj_data.csv]
2024-09-09 added comments
    [trj_data.csv]
2024-09-10 trajectory generator optimized
    [configuration.h, trj_data.csv]
2024-09-10 update dr
    [configuration.h, trj_data.csv]
2024-09-11 a lot of changes
    [configuration.h, trj_data.csv]
2024-09-12 added motion planning fsm
    [configuration.h, trj_data.csv]
2024-09-28 changed folder path
    [17HS24-2004D-E1K.STEP, NUCLEO64-F401RE.kicad_sch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]
